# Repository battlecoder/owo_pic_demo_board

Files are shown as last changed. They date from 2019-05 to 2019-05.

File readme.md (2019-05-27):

# OWO PIC Demo Board
This is a very simple demo board I designed around one of my favorite microcontrollers: The PIC 16F628A from Microchip.
I also wrote a small "framework" in asm for it, that handles the display, buttons, serial comm, text scrolling, etc, and I've included a simple implementation of Tetris as an example of its usage.

You'll find the schematic and board layout (KiCad) of the *OWO board* in the **/board** folder. There's a lot that can be improved but it works as it is. The demo code and framework/boilerplate is in the **/asm_demo_code** directory.

You can see a video of one the early builds of the Tetris demo running on the board:
<blockquote class="twitter-tweet"><p lang="en" dir="ltr">Tetris implemented in assembly on the PIC16F628A demo board I designed a few months ago. <a href="https://twitter.com/hashtag/electronics?src=hash&amp;ref_src=twsrc%5Etfw">#electronics</a> <a href="https://twitter.com/hashtag/DIY?src=hash&amp;ref_src=twsrc%5Etfw">#DIY</a> <a href="https://twitter.com/hashtag/assemblycode?src=hash&amp;ref_src=twsrc%5Etfw">#assemblycode</a> <a href="https://twitter.com/hashtag/microchip?src=hash&amp;ref_src=twsrc%5Etfw">#microchip</a><br></p>&mdash; Elias Zacarias (@battlecoder)<a href="https://twitter.com/battlecoder/status/1109868608677707781?ref_src=twsrc%5Etfw">March 24, 2019</a></blockquote>

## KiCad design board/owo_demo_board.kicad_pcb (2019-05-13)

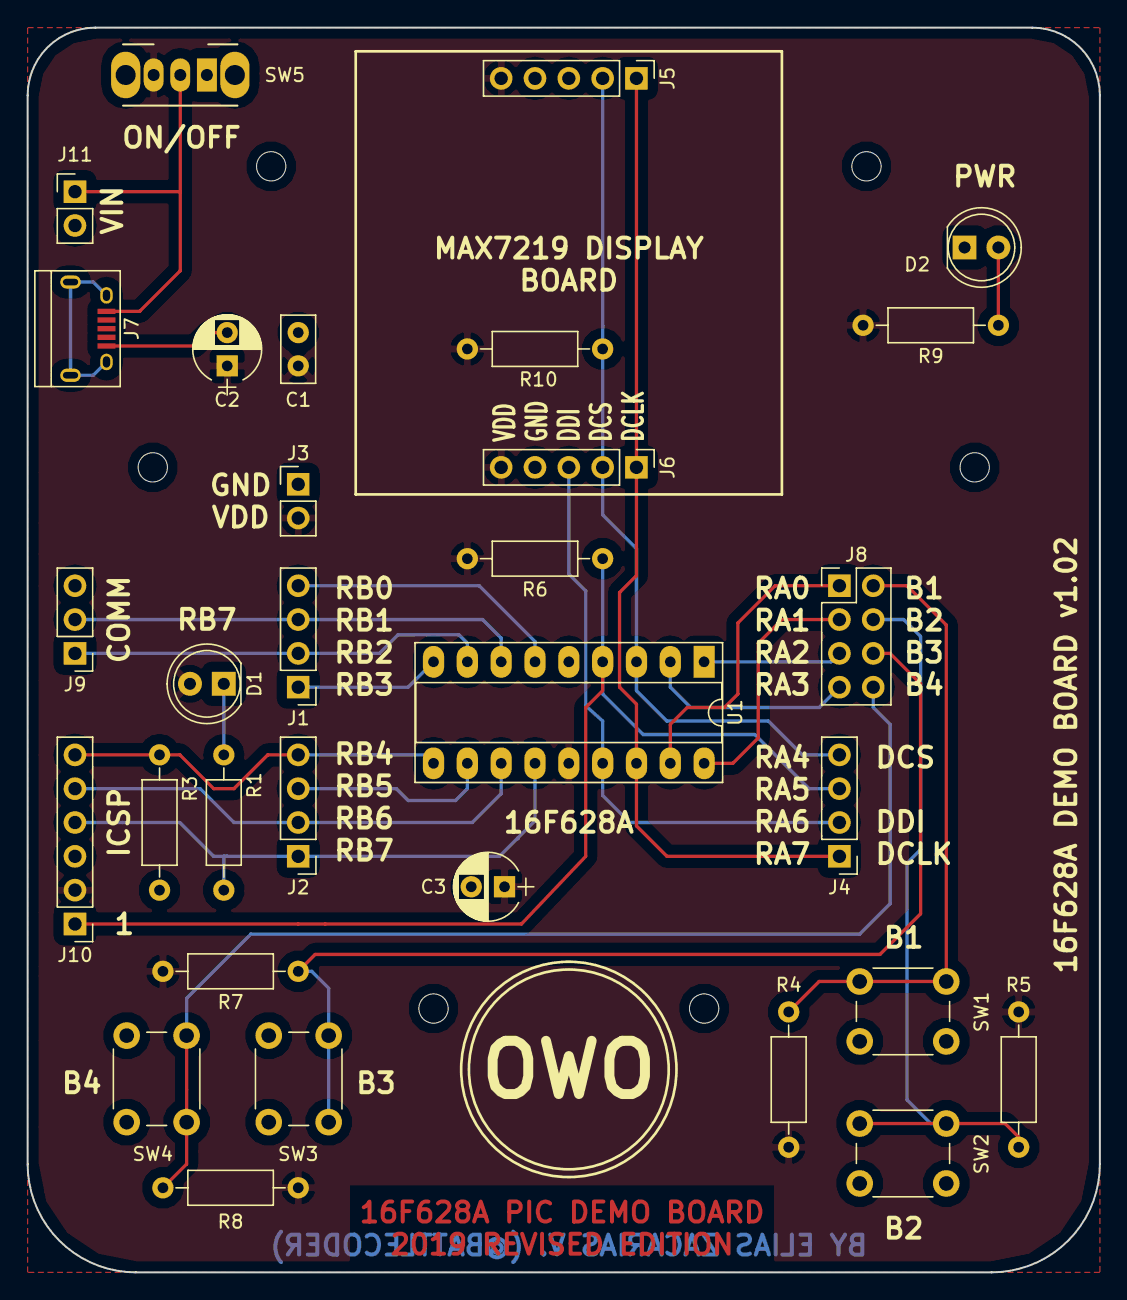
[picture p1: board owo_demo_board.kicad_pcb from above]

Board: 2 copper layers, 80.5 x 93.5 mm, 31 parts (0 on the bottom side), 25 nets.

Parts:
C1: 0.1uF; C_Disc_D5.0mm_W2.5mm_P2.50mm
C2: 10uF; CP_Radial_D5.0mm_P2.50mm
C3: 1uF; CP_Radial_D5.0mm_P2.50mm
D1, D2: LED; LED_D5.0mm
J1: RB0-3; Pin_Header_Straight_1x04_Pitch2.54mm
J2: RB4-7; Pin_Header_Straight_1x04_Pitch2.54mm
J3: PWR_CONN; Pin_Header_Straight_1x02_Pitch2.54mm
J4: RA4-7; Pin_Header_Straight_1x04_Pitch2.54mm
J5: DISPLAY_1; Pin_Header_Straight_1x05_Pitch2.54mm
J6: DISPLAY_2; Pin_Header_Straight_1x05_Pitch2.54mm
J7: USB_OTG; USB_Micro-B
J8: CONN_02X04; Pin_Header_Straight_2x04_Pitch2.54mm
J9: COMM; Pin_Header_Straight_1x03_Pitch2.54mm
J10: ICSP; Pin_Header_Straight_1x06_Pitch2.54mm
J11: VIN; Pin_Header_Straight_1x02_Pitch2.54mm
R1: 4K7; R_Axial_DIN0207_L6.3mm_D2.5mm_P10.16mm_Horizontal
R3, R4, R5, R6, R7, R8, R10: 10K; R_Axial_DIN0207_L6.3mm_D2.5mm_P10.16mm_Horizontal
R9: 330; R_Axial_DIN0207_L6.3mm_D2.5mm_P10.16mm_Horizontal
SW1: B1; SW_PUSH_6mm
SW2: B2; SW_PUSH_6mm
SW3: B3; SW_PUSH_6mm
SW4: B4; SW_PUSH_6mm
SW5: SW_DPDT_x2; SW_CuK_OS102011MA1QN1_SPDT_Angled
U1: PIC16(L)F628A-I/P; DIP-18_W7.62mm_Socket_LongPads

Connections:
DIS_CLK: J4.1, J5.1, J6.1, U1.16
DIS_CS: J4.4, J5.2, J6.2, R10.1, U1.3
DIS_DI: J4.2, J6.3, U1.15
GND: C1.2, C2.2, C3.2, D2.1, J3.1, J5.4, J6.4, J7.5, J9.3, J10.3, J11.2, R3.1, SW1.2, SW2.2, SW3.2, SW4.2, U1.5
unnamed: D1.1, R1.2
unnamed: D2.2, R9.1
unnamed: J8.2, R4.1, SW1.1
unnamed: J8.4, R5.1, SW2.1
unnamed: J8.6, R7.1, SW3.1
unnamed: J8.8, R8.1, SW4.1
unnamed: J7.1, J11.1, SW5.2
RA0: J8.1, U1.17
RA1: J8.3, U1.18
RA2: J8.5, U1.1
RA3: J8.7, U1.2
RA5/_MCLR: J4.3, J10.1, R6.1, U1.4
RB0: J1.4, U1.6
RB1/RX: J1.3, J9.2, U1.7
RB2/TX: J1.2, J9.1, U1.8
RB3: J1.1, U1.9
RB4/PGM: J2.4, J10.6, R3.2, U1.10
RB5: J2.3, U1.11
RB6/PGC: J2.2, J10.5, U1.12
RB7/PGD: J2.1, J10.4, R1.1, U1.13
VDD: C1.1, C2.1, C3.1, D1.2, J3.2, J5.5, J6.5, J10.2, R4.2, R5.2, R6.2, R7.2, R8.2, R9.2, R10.2, SW5.3, U1.14

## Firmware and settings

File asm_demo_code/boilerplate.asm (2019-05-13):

; #############################################################################
; 
; File   : boilerplate.asm
; Author : Elias Zacarias
; 
; #############################################################################
; This file contains all the code I wrote for the OWO PIC DEMO Board Workshop,
; and includes snippets of code for the following:
;
; Buttons ---------
; There's a subroutine for reading the hardware buttons (read_buttons). This
; will maintain the following information in file registers:
;   - down_bttns   : Buttons currently pressed
;   - last_bttns   : Buttons that were pressed previously
;   - new_bttn_dwn : Buttons that were not previously pressed, but are pressed
; now.
; The BUTTON_XXXX constants have the bit from those bytes that correspond to
; each physical button.
;
; 8x8 LED Matrix --
; The data for the screen is held in a framebuffer (vmem) from which it can be
; read/written at any time. The physical screen is controlled by a MAX7219 IC
; and is updated via a 60Hz interrupt (this frequency can be changed; check
; start_refrsh_timer). There  are some subroutines to control the driver IC
; directly, but the main subs you will probably want to use are:
;   - vmem_set_pixel   : Turns on a single pixel on the screen.
;   - vmem_clear_pixel : Turns off a single pixel from the screen.
;   - vmem_get_col     : Gets a whole column (8 bits) of pixel data at once.
;   - vmem_set_col     : Sets a whole column of pixels at once.
;   - vmem_fill        : Completely fills the screen (sets all pixels to 1)
;   - vmem_clear       : Completely clears the screen (sets all pixels to 0)
;
; Serial Port -----
; There´s several functions for the hardware serial port.
;   - USART_init         : Initializes the Hardware USART controller.
;   - USART_block_send   : Sends a byte of data. Waits until it has been sent.
;   - USART_send         : Sends a byte of data asynchronously.
;   - USART_recv         : Gets one byte of data if available.
;   - USART_recv_pending : Checks whether there's unread data in the IN buffer
;
; EEPROM ----------
; There´s also a few basic functions to read and write to the onboard EEPROM
; and store information like hi-scores, settings, etc.
;   - eeprom_read  : Reads one byte from EEPROM
;   - eeprom_write : Writes one byte to EEPROM
;
; Font / Text -----
; Additionally I wrote code to handle printing texts on screen based on PGM 
; tables. Tge following subroutines are the most useful:
;   - vmem_draw_char : Draws a char from the font table
;   - scroll_text_fx : Scrolls a text string on the screen.
; I also included a macro (scroll_text) and a demo of how to use it on this
; file. It greatly simplifies displaying text strings.
;
; Frame control ---
; The screen refresh interrupt will always decrease a counter that you can use
; to time your game logic. There is an auxiliary function (delay_w_frames) that
; uses that to pause the execution for a given number of frames.

    LIST p=16F628A          ; Tell assembler what micro is in use
    include "P16F628A.inc"  ; Include definitions for this device

	__config _CP_OFF & _PWRTE_ON & _WDT_OFF & _INTRC_OSC_NOCLKOUT & _MCLRE_ON

    RADIX   DEC ; Default base for numbers is Decimal
    ERRORLEVEL -1302; Disable the assembler messages for RAM bank check

; Data addresses definition  ---------------------
cblock H'20'     ; Start of general purpose registers
    ; Framework data ----------
	vmem:8		; "Video" memory

    dd_addr     ; Data Address used for display data transmission
    dd_data     ; Data used for display data transmission
    dd_byte     ; Temp byte to send
    dd_cnt      ; Bit counter for display data transmission

    last_bttns  ; Keeps track of pressed buttons, and those
    down_bttns  ; that changed from last reading.
    new_bttn_dwn; 

    scroll_strhi; Scrolling text parameter: HIGH address of string table
    scroll_strlo; Scrolling text parameter: LOW address of string table
    scroll_strsz; Scrolling text parameter: String size (length)

    st_str_off  ; Scrolling text, string offset
    st_max_off  ; Scrolling text, max offset
    st_char_ndx ; Scrolling text char index
    st_col_ref  ; Scrolling text column reference

    font_char   ; font character
    font_ndx    ; Actual font char index in table
    char_col    ; font column

	shift_cnt	; Variables for bit shifting
	shift_val	; operation

    vmem_col	; Variables for some VRAM 
	vmem_row	; routines and operations
	vmem_data	;
endc

; Make sure the following registers are at the bottom area of the RAM,
; so they can be accessed from any page.
w_bkup         equ     H'7f'
status_bkup    equ     H'7e'
eeprom_addr    equ     H'7d'
frame_tick     equ     H'7c'
frame_cntdown  equ     H'7b'

; Constants
FIRST_FONT_CHAR   equ     ' '
LAST_FONT_CHAR    equ     '`'
BUTTONS_MASK      equ     B'00001111' ; We want to read all four buttons
                                      ; Connected to RA3:RA0

BUTTON_UP         equ   0
BUTTON_DOWN       equ   1
BUTTON_RIGHT      equ   2
BUTTON_LEFT       equ   3

; ---- I/O PINS ---------------
M7219_PORT        equ     PORTA
M7219_DIN         equ     6
M7219_CLK         equ     7
M7219_NOTCS       equ     4

BUTTONS_PORT      equ     PORTA

LED_PIN           equ     7

; --- Other Settings -----------
DISPL_BRIGHTNESS  equ     0     ; A value from 0 to 0xF -- 0 is already bright enough.
                                ; Check max7219_init to see how you can change this at runtime, if desired.

; Display driver (MAX7219) commands
M7219_DECODE      equ     H'9'
M7219_INTENSITY   equ     H'A'
M7219_SCANLIMIT   equ     H'B'
M7219_SHUTDOWN    equ     H'C'
M7219_TEST        equ     H'F'

; #######################################################################
; ##                                                                   ##
; ##                            M A C R O S                            ##
; ##                                                                   ##
; #######################################################################
; -----------------------------------------------------------------------
; [MACRO] scroll_text
;   Scrolls text defined at PGM address string_table, with (const) length
;   str_len_c
; -----------------------------------------------------------------------
scroll_text macro string_table, str_len_c
    movlw   HIGH(string_table)
    movwf   scroll_strhi

    movlw   LOW(string_table)
    movwf   scroll_strlo

    movlw   str_len_c
    movwf   scroll_strsz
    
    call    scroll_text_fx
    endm

; -----------------------------------------------------------------------
; [MACRO] shift_right_w_f
;   Shifts the value of W, file_f places to the right. Returns with
;   value on W. Not really efficient but it works.
; -----------------------------------------------------------------------
shift_right_w_f macro file_f
	local	_rsh_loop
	local	_rsh_end
	movwf	shift_val
	movf	file_f, W
	movwf	shift_cnt
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
